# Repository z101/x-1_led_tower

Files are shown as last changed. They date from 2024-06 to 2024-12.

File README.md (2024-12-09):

# x-1_led_tower
This is an electronic LED sculpture project, stylized as some generic telecommunication tower and inspired by @mohitbhoite cool works.
The project will be break down to next parts:
1. **Electronic circuit**. Developed in KiCAD. Circuit from Frank Sichla's book. SPICE models for simulation taken from Internet
2. **3D model**. Developed in FreeCAD
3. **Assembly**. The most interesting part - building sculpture itself

## KiCAD circuit version 1
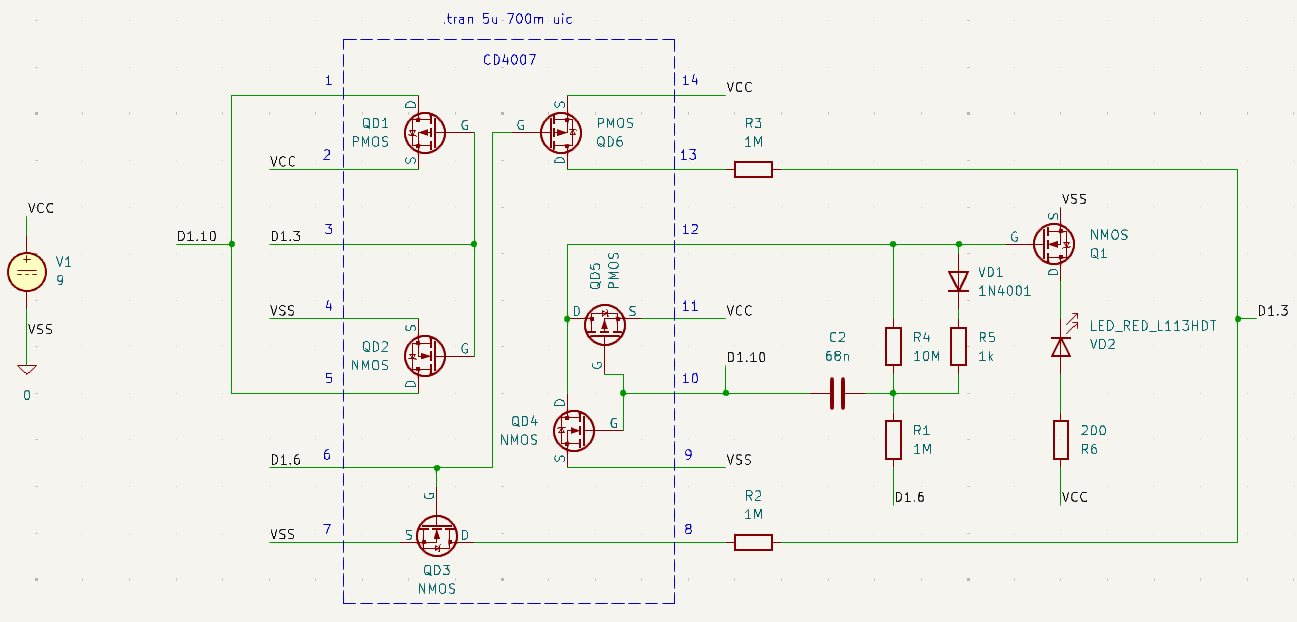
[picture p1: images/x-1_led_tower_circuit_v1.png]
x-1_led_tower circuit v1 KiCAD prototype


## KiCAD circuit SPICE flash spike simulation version 1
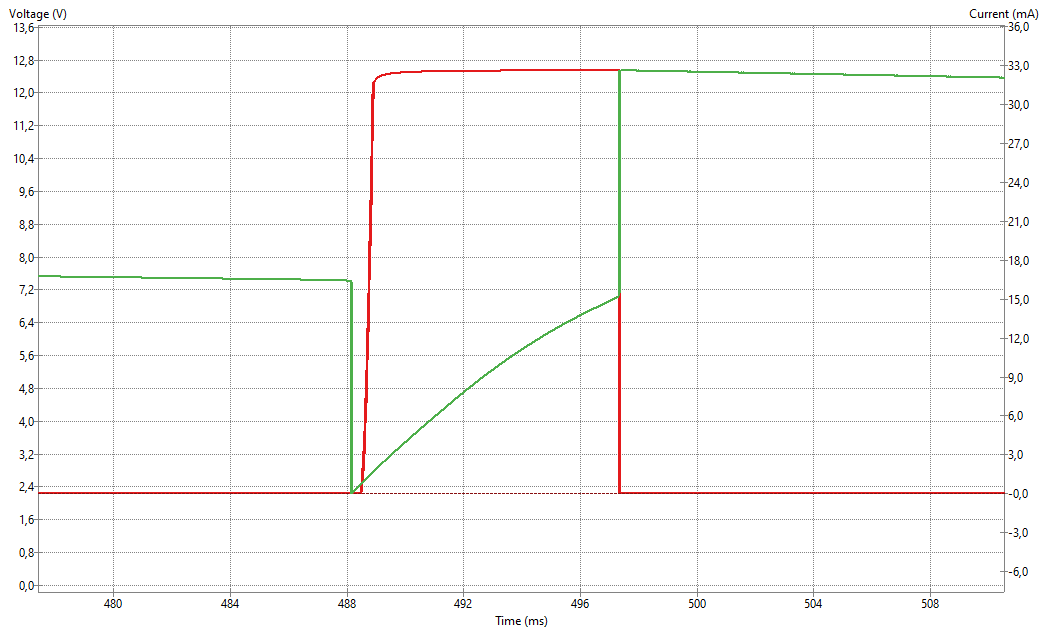
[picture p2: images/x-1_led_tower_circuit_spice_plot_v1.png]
x-1_led_tower circuit SPICE Simulation Plot v1 KiCAD prototype


## FreeCAD 3D prototype version 1
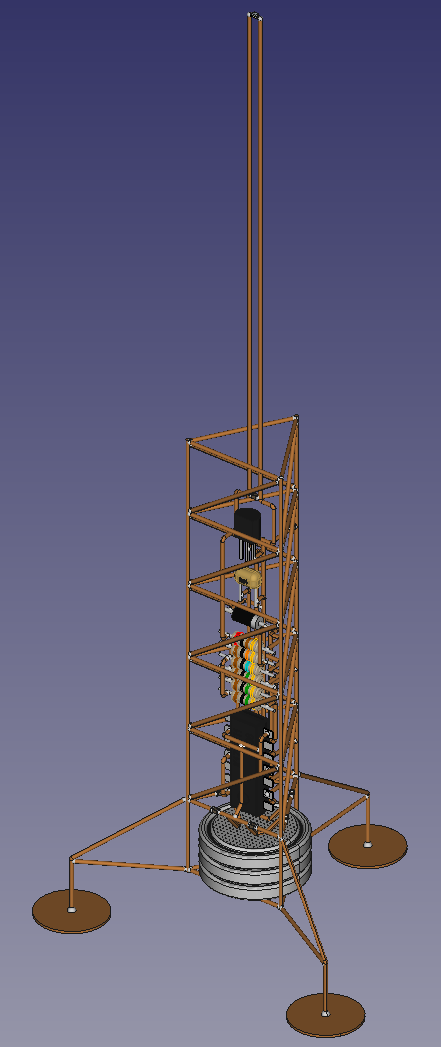
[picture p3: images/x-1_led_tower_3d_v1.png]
x-1_led_tower 3d v1 FreeCAD prototype


## Initial conditions changed
Due to a number of reasons, I can't solder at home yet. Therefore, I decided to redesign the tower project for assembly via crimping.

## FreeCAD 3D prototype version 2
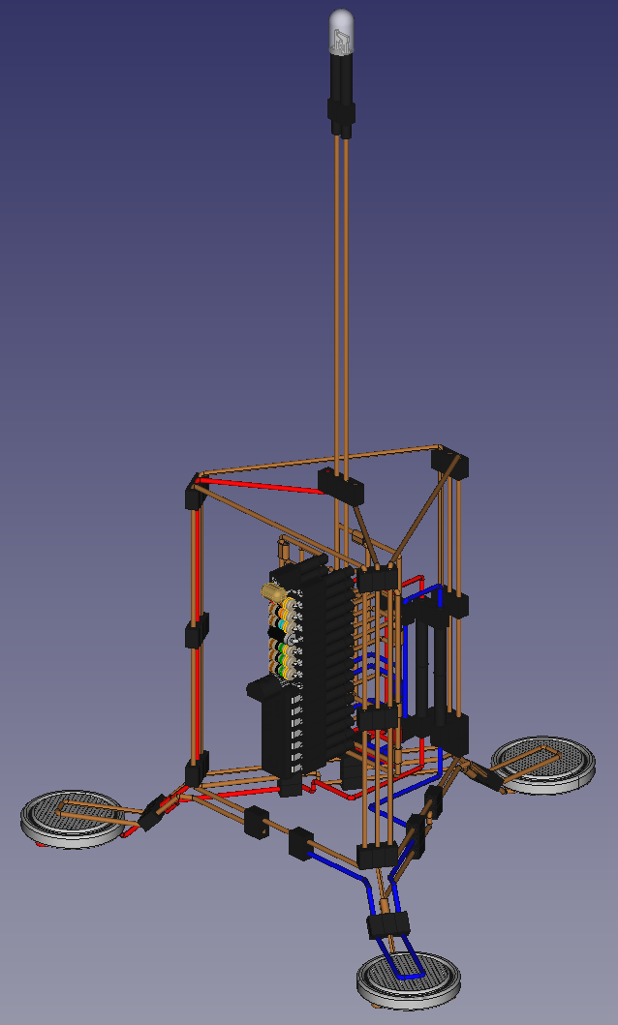
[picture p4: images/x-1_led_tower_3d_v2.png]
x-1_led_tower 3d v2 FreeCAD prototype


## FreeCAD 3D prototype version 2 assembly (failed)
Assembling the sculpture neatly using the blueprints of v2 turned out to be too difficult for me.  
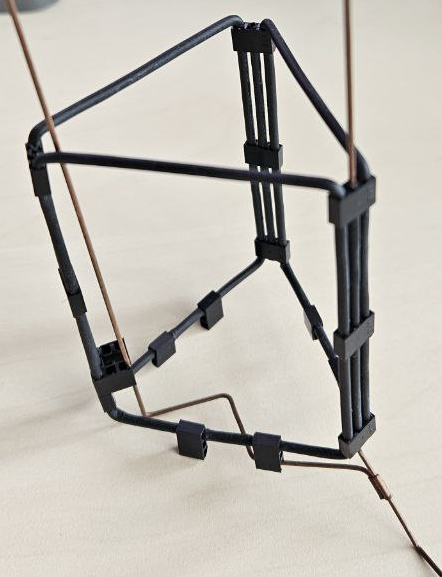
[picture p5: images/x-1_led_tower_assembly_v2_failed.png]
x-1_led_tower assembly v2 failed


## FreeCAD 3D prototype version 3
I abandoned v2 and decided to remake it into v3 - lightweight and simplified.  
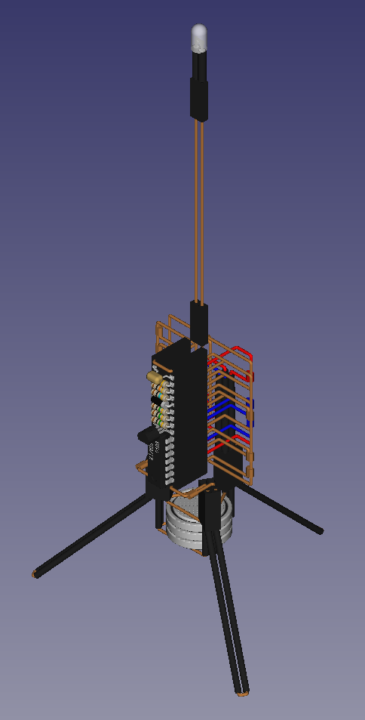
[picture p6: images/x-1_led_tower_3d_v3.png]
x-1_led_tower 3d v3 FreeCAD prototype


## FreeCAD 3D prototype version 3 assembly (failed)
Another fail with assembling triangle holder and bending. Threw it away...

## FreeCAD 3D prototype version 4
Another remake v4 - simplified for assembly  
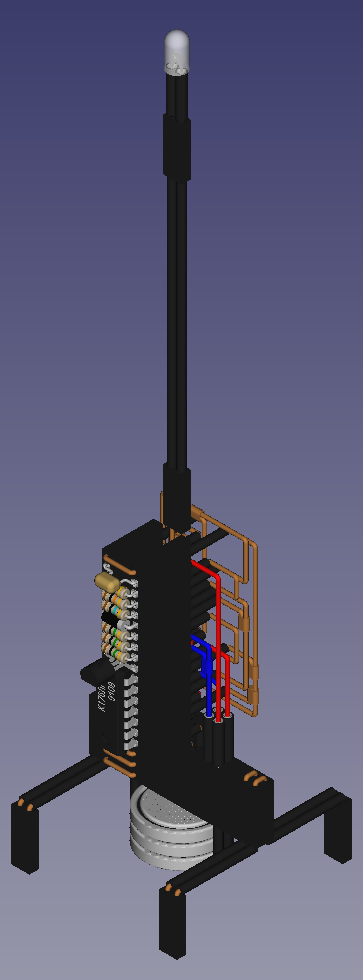
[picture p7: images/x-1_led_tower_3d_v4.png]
x-1_led_tower 3d v4 FreeCAD prototype


## FreeCAD 3D prototype version 4 assembly (abandoned)
I started the assembly, but only made the base, because I found a way to go back to soldering, to the original version of the sculpture.  
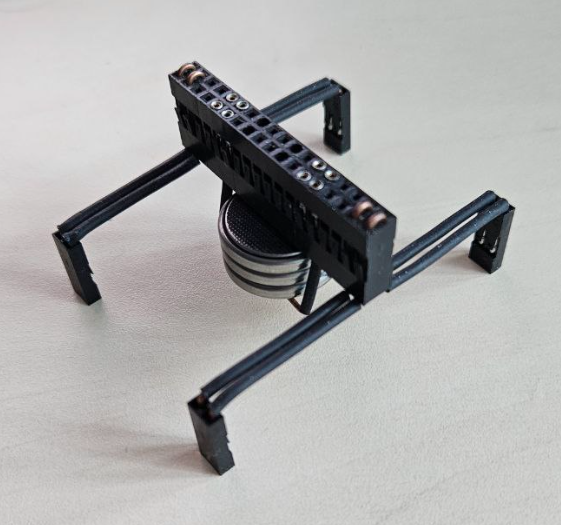
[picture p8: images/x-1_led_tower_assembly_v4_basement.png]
x-1_led_tower assembly v4 basement


## FreeCAD 3D prototype version 1.1
At first I tried soldering with pine rosin. The joints were quite neat, but there was too much solid rosin residue that could not be washed off with isopropyl alcohol, and it was not possible to remove all the residue mechanically. I gave up on this flux.  
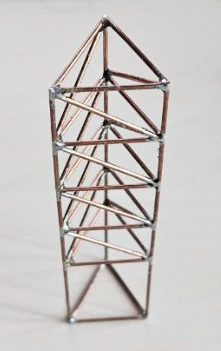
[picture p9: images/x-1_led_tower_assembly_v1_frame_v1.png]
x-1_led_tower assembly v1 frame v1


## FreeCAD 3D prototype version 1.1 (new flux)
I switched to liquid flux from Interflux (RP-65). I applied it with an applicator with a brush. The joints turned out nice and clean. But I failed again on soldering the negative battery holder. The 0603 SMD capacitors I wanted to use as separators turned out to be too fragile, the leads were torn off under load. So I decided to abandon the original idea again and move on to version 5 of the sculpture with a completely redesigned battery holder.  
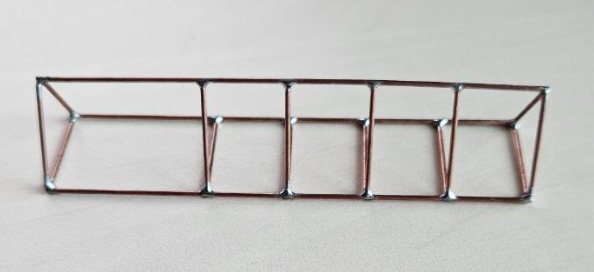
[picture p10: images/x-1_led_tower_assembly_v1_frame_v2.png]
x-1_led_tower assembly v1 frame v2


## FreeCAD 3D prototype version 5
Another remake v5 - improved battery holders and overall sculpture view.  
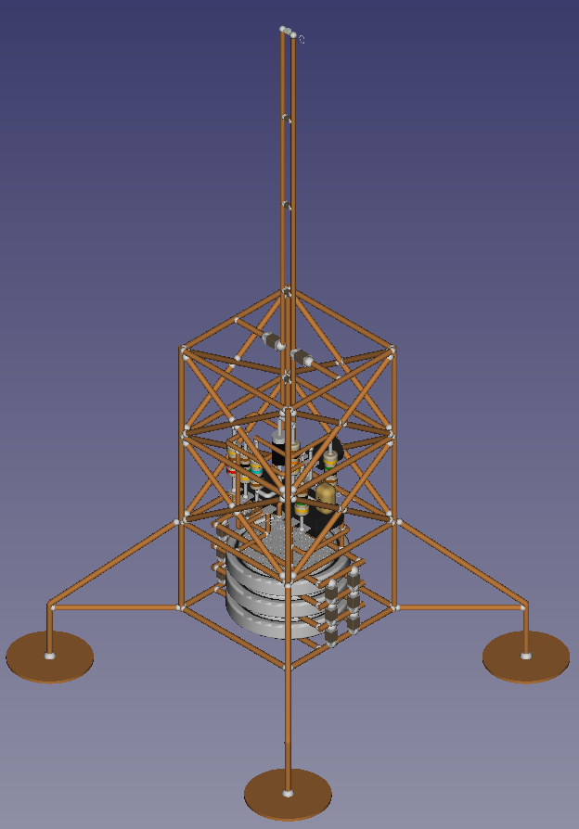
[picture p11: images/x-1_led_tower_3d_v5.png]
x-1_led_tower 3d v5 FreeCAD prototype


## FreeCAD 3D prototype version 5 assembly (failed)
I started the build of version 5 with the battery holder as the most controversial part of the design. The goal was to get independent sections for each CR2032. Unfortunately, the ceramic 1206 SMD decoupling capacitors fell apart when I inserted the batteries.  
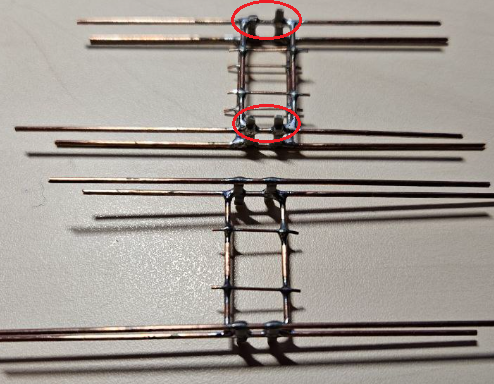
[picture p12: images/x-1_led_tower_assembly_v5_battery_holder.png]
x-1_led_tower assembly v5 battery holder


## FreeCAD 3D prototype version 5.1
Another remake v5.1 - combined battery holder (with fewer SMD 1206 capacitors).  
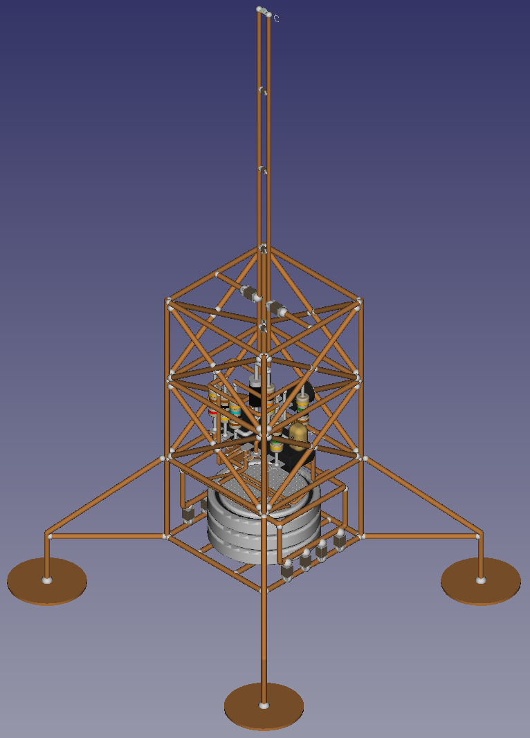
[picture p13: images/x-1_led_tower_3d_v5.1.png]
x-1_led_tower 3d v5.1 FreeCAD prototype


## FreeCAD 3D prototype version 5.1 assembly (failed)
The assembly of the holder of this version also failed. Even at the soldering stage. The SMD capacitors turned out to be too thin and fragile, and fell apart when trying to solder the holder to the side of the frame.  
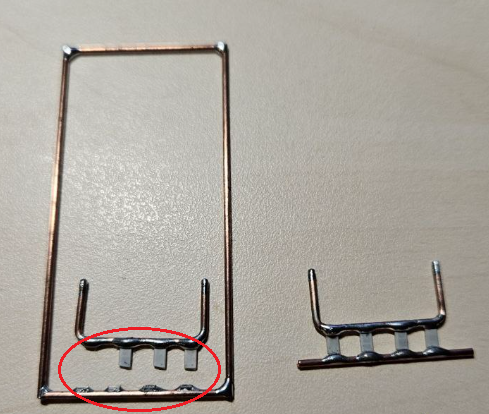
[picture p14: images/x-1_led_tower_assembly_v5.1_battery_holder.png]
x-1_led_tower assembly v5.1 battery holder


## FreeCAD 3D prototype version 5.2
Another remake v5.2 - replacing SMD capacitors by its DIP analogs.  
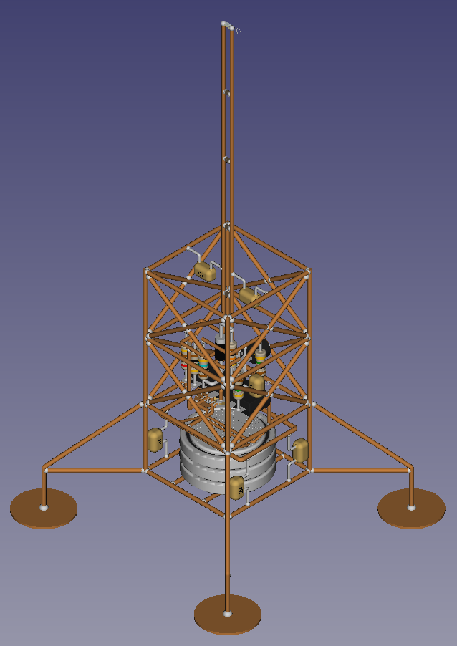
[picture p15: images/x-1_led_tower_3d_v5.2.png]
x-1_led_tower 3d v5.2 FreeCAD prototype


## FreeCAD 3D prototype version 5.2 assembly (success, finally! :)
At first I wanted to replace the thin and fragile 1206 capacitors with thiker 1210 ones. But then I decided to use "more durable" DIP ceramic capacitors with low capacitance. With them I managed to successfully complete soldering the entire sculpture.  
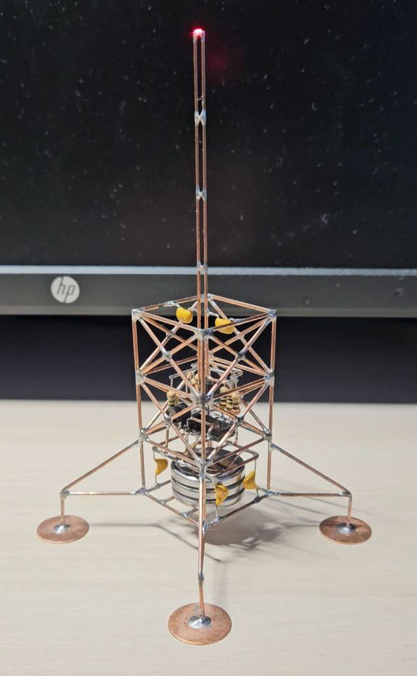
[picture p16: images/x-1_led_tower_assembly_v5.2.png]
x-1_led_tower assembly v5.2
  

## Simulation vs Reality
The simulated results of the voltage drop on the resistor R6 at the moment of LED flashes in KiCAD practically the same with the actual values taken by the Rigol oscilloscope (DHO814). However, the frequency of flashes is very different: ~1.5 Hz for simulation and ~0.25 Hz for the real circuit. I haven't figured out the reasons yet - I decided to leave it as is. The blinking is not annoying. Let's see how long it works without replacing the batteries.  
  
Simulated R6 flash voltage drop:  
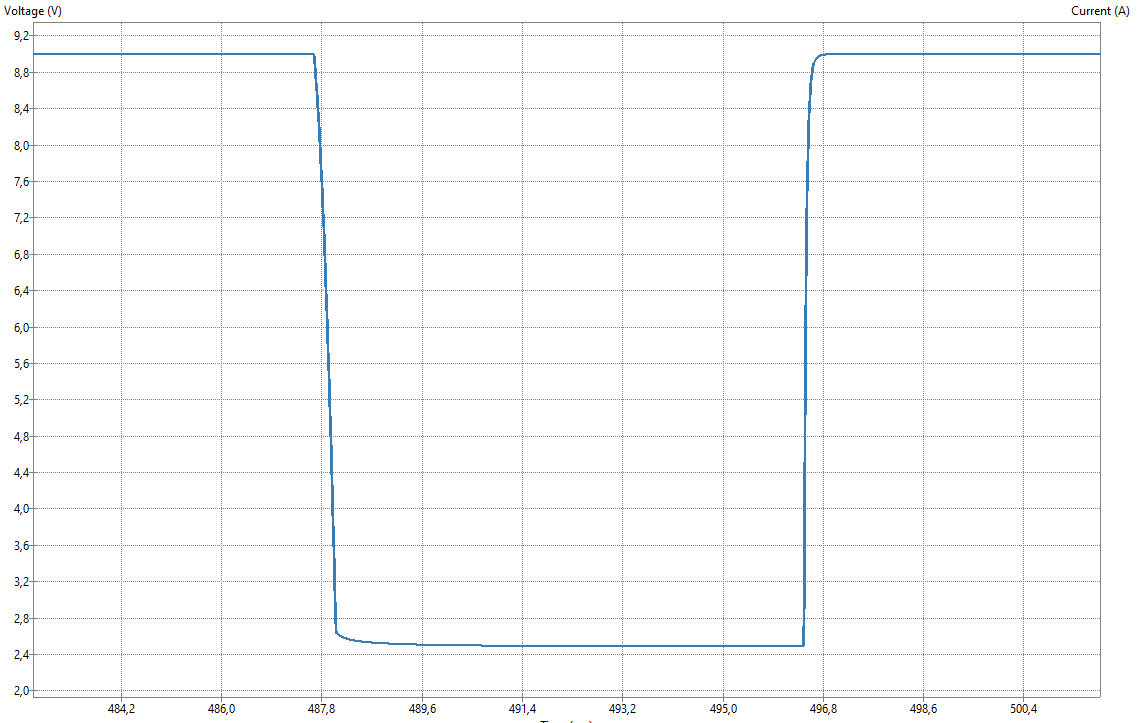
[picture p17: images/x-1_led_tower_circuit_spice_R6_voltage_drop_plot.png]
x-1_led_tower_circuit_spice_R6_voltage_drop_plot
  
  
Real R6 flash voltage drop:  
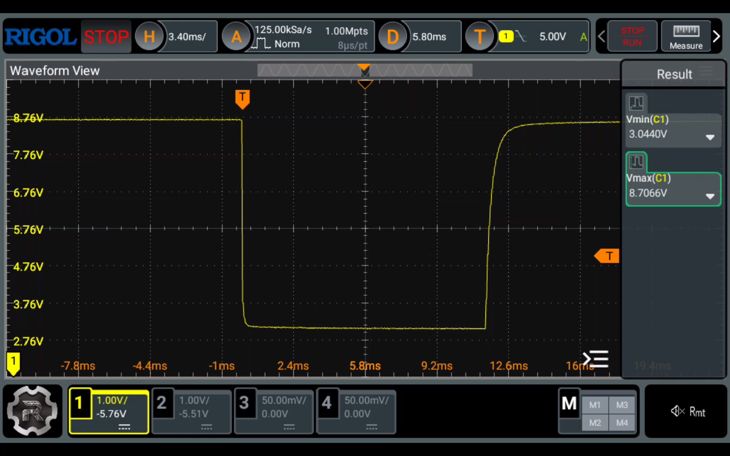
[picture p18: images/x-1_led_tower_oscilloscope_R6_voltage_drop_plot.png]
x-1_led_tower_oscilloscope_R6_voltage_drop_plot
  

## Summary
Overall, I am pleased with the result. The circuit is, of course, very trivial. But it is OK for the first time.  
  
 - **What I liked about assembling the sculpture**
   - I liked to solder with liquid flux Interflux RF65. It is very convenient to apply with an applicator with a brush. It does not smell, have no residue indeed
   - The following really helped in the work: a jewelry third hand, a steel plate with round neodymium magnets, a steel corner plate, thin curved tweezers
   - The wire frame looks nice
 - **What needs to be worked on**
   - The soldering quality is still terrible and far from beautiful joints - I need to practice more (especially when many conductors converge at one point). Considering that this is my first experience in soldering, there is room for growth :)
   - The wire with a diameter of 1 mm is too thick for the frame. In the future, I will try 0.8 mm
   - The assembly quality of the circuit itself (from DIP parts). The assembly of the circuit does not look neat. It is necessary to think about "flattening" using medium or large size SMD components (so that their soldering is not a pain)

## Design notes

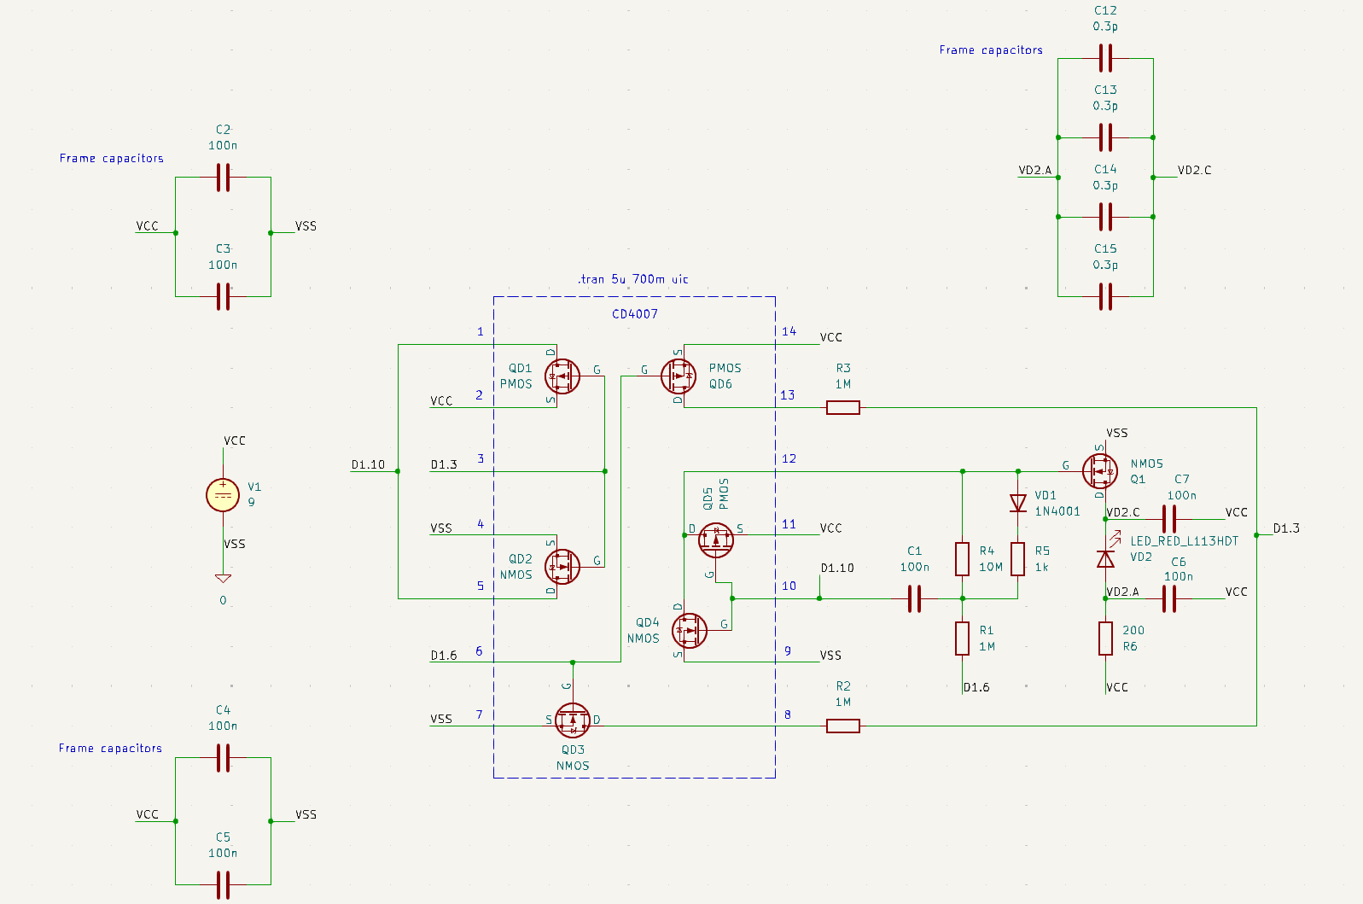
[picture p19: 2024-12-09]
images/x-1_led_tower_circuit_v1.1.png

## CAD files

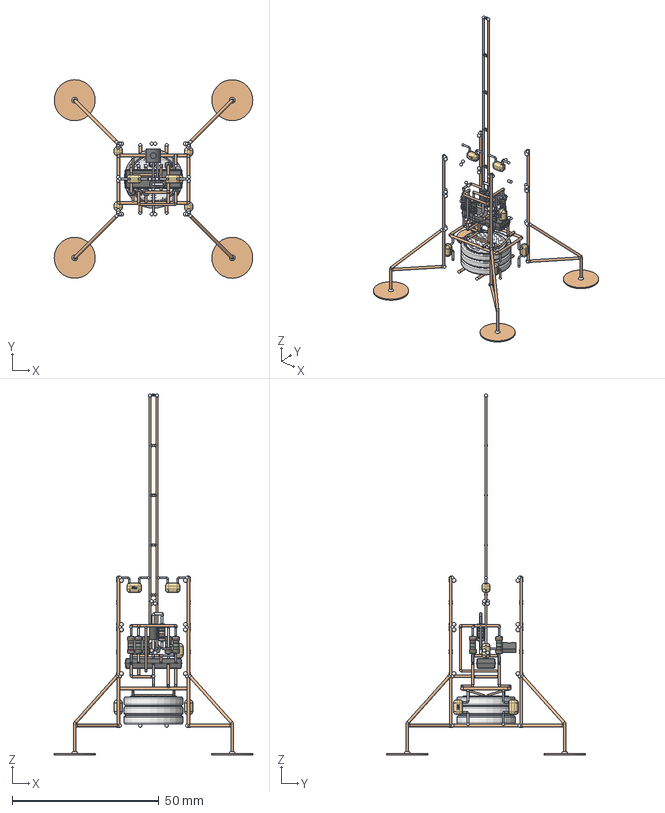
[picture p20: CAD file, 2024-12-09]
3d/x-1_led_tower.v5.2.FCStd
67.7 x 67.7 x 123.0 mm
Pillar Right - Basement
Basement Plus - Basement Front028
Basement Plus - Basement Front025
Pillar Right - Basement002
Pillar Right - Basement001
Basement Plus - Basement Front026
Basement Plus - Basement Front027
Pillar Right - Basement003
Pillar Back - Soldering Bottom Near011
Pillar Right - Basement Soldering
Pillar Right - Basement Soldering003
Pillar Back - Soldering Bottom Near012
Pillar Back - Soldering Bottom Near010
Pillar Back - Soldering Bottom Near005
Pillar Back - Soldering Bottom Near001
Pillar Back - Soldering Bottom Near002
Pillar Back - Soldering Bottom Near003
Pillar Right - Basement Soldering001
Pillar Back - Soldering Bottom Near004
Pillar Back - Soldering Bottom Near006
Pillar Right - Basement Soldering002
Pillar Back - Soldering Bottom Near007
Pillar Back - Soldering Bottom Near008
Pillar Back - Soldering Bottom Near009
Vertical 1
Vertical 002
Vertical 003
Vertical 004
Basement Plus - Basement Front007
Basement Plus - Basement Front006
Vertical 009
Basement Plus - Basement Front032
Vertical 010
Basement Plus - Basement Front033
Basement Plus - Basement Front034
Basement Plus - Basement Front035
Vertical 011
Basement Plus - Basement Front036
Vertical 012
Basement Plus - Basement Front037
Pillar Back - Soldering Bottom Far010
Pillar Back - Soldering Bottom Far014
Pillar Back - Soldering Bottom Far018
Pillar Back - Soldering Bottom Far022
Pillar Back - Soldering Bottom Far224
Pillar Back - Soldering Bottom Far225
Pillar Back - Soldering Bottom Far226
Pillar Back - Soldering Bottom Far227
Pillar Back - Soldering Bottom Far232
Pillar Back - Soldering Bottom Far233
Pillar Back - Soldering Bottom Far234
Pillar Back - Soldering Bottom Far235
Pillar Back - Soldering Bottom Far236
Pillar Back - Soldering Bottom Far237
Pillar Back - Soldering Bottom Far238
Pillar Back - Soldering Bottom Far239
Insulator
Minus
Plus
Insulator_2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

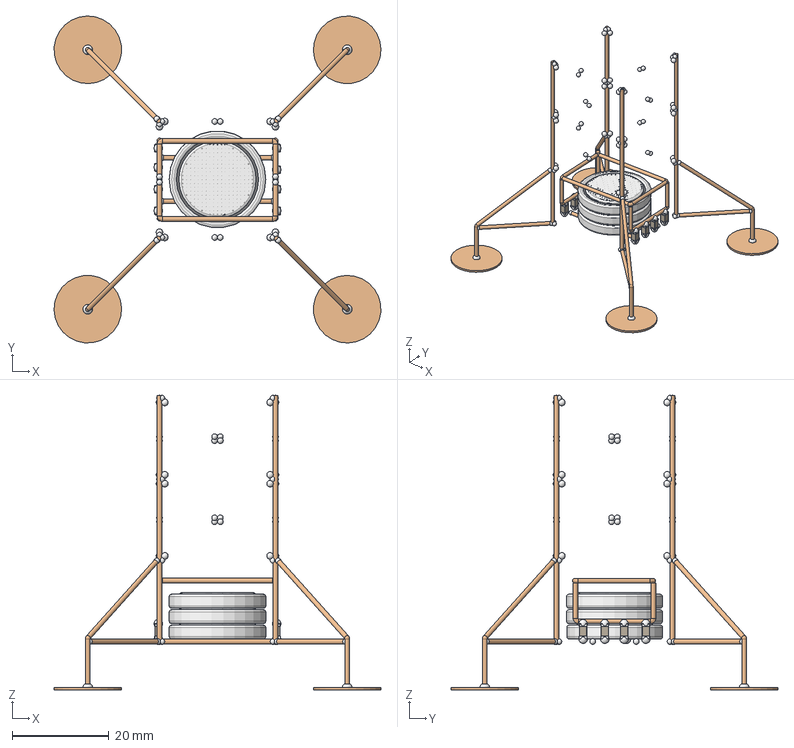
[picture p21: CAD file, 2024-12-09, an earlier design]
3d/x-1_led_tower.v5.FCStd
67.7 x 67.7 x 61.0 mm
Pillar Right - Basement
Basement Plus - Basement Front028
Basement Plus - Basement Front025
Pillar Right - Basement002
Pillar Right - Basement001
Basement Plus - Basement Front026
Basement Plus - Basement Front027
Pillar Right - Basement003
Pillar Back - Soldering Bottom Near011
Pillar Right - Basement Soldering
Pillar Right - Basement Soldering003
Pillar Back - Soldering Bottom Near012
Pillar Back - Soldering Bottom Near010
Pillar Back - Soldering Bottom Near005
Pillar Back - Soldering Bottom Near001
Pillar Back - Soldering Bottom Near002
Pillar Back - Soldering Bottom Near003
Pillar Right - Basement Soldering001
Pillar Back - Soldering Bottom Near004
Pillar Back - Soldering Bottom Near006
Pillar Right - Basement Soldering002
Pillar Back - Soldering Bottom Near007
Pillar Back - Soldering Bottom Near008
Pillar Back - Soldering Bottom Near009
Vertical 1
Vertical 002
Vertical 003
Vertical 004
Basement Plus - Basement Front007
Basement Plus - Basement Front006
Basement Plus - Basement Front010
Pillar Back - Soldering Bottom Far010
Pillar Back - Soldering Bottom Far014
Pillar Back - Soldering Bottom Far018
Pillar Back - Soldering Bottom Far022
Pillar Back - Soldering Bottom Far030
Pillar Back - Soldering Bottom Far032
Pillar Back - Soldering Bottom Far033
Pillar Back - Soldering Bottom Far034
Pillar Back - Soldering Bottom Far035
Pillar Back - Soldering Bottom Far036
Контакты002
Корпус002
Контакты
Корпус
Контакты001
Корпус001
Контакты003
Корпус003
Insulator
Minus
Plus
Insulator_2
Minus_2
Plus_2
Insulator_3
Minus_3
Plus_3
Pillar Back - Soldering Bottom Far047
Pillar Back - Soldering Bottom Far048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

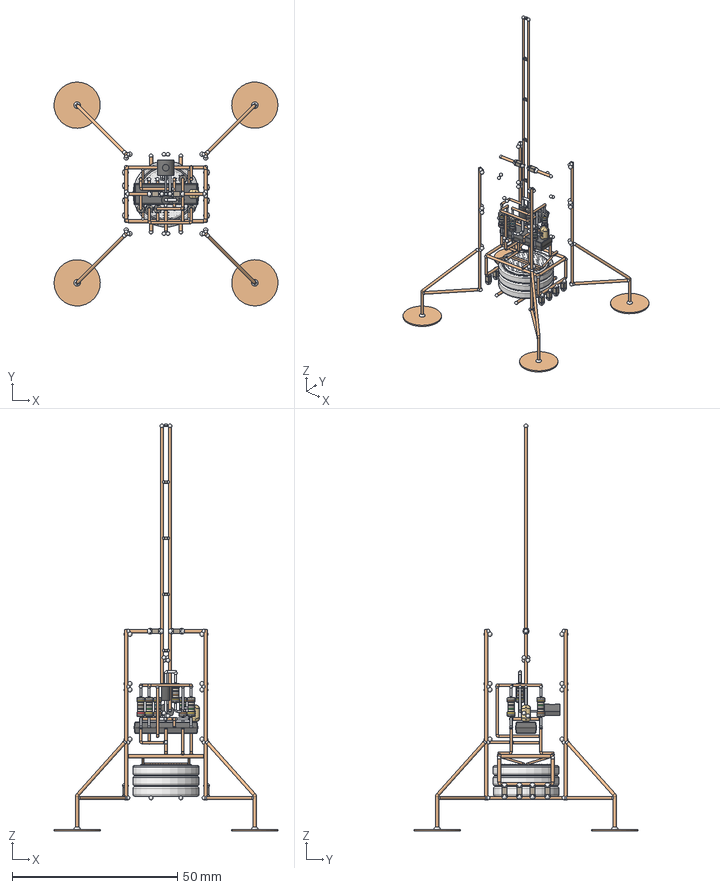
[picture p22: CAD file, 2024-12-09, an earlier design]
3d/x-1_led_tower.v5.1.FCStd
67.7 x 67.7 x 123.0 mm
Pillar Right - Basement
Basement Plus - Basement Front028
Basement Plus - Basement Front025
Pillar Right - Basement002
Pillar Right - Basement001
Basement Plus - Basement Front026
Basement Plus - Basement Front027
Pillar Right - Basement003
Pillar Back - Soldering Bottom Near011
Pillar Right - Basement Soldering
Pillar Right - Basement Soldering003
Pillar Back - Soldering Bottom Near012
Pillar Back - Soldering Bottom Near010
Pillar Back - Soldering Bottom Near005
Pillar Back - Soldering Bottom Near001
Pillar Back - Soldering Bottom Near002
Pillar Back - Soldering Bottom Near003
Pillar Right - Basement Soldering001
Pillar Back - Soldering Bottom Near004
Pillar Back - Soldering Bottom Near006
Pillar Right - Basement Soldering002
Pillar Back - Soldering Bottom Near007
Pillar Back - Soldering Bottom Near008
Pillar Back - Soldering Bottom Near009
Vertical 1
Vertical 002
Vertical 003
Vertical 004
Basement Plus - Basement Front007
Basement Plus - Basement Front006
Basement Plus - Basement Front010
Vertical 005
Vertical 006
Vertical 007
Vertical 008
Basement Plus - Basement Front031
Vertical 009
Basement Plus - Basement Front032
Vertical 010
Basement Plus - Basement Front033
Basement Plus - Basement Front034
Basement Plus - Basement Front035
Vertical 011
Basement Plus - Basement Front036
Vertical 012
Basement Plus - Basement Front037
Pillar Back - Soldering Bottom Far010
Pillar Back - Soldering Bottom Far014
Pillar Back - Soldering Bottom Far018
Pillar Back - Soldering Bottom Far022
Pillar Back - Soldering Bottom Far030
Pillar Back - Soldering Bottom Far032
Pillar Back - Soldering Bottom Far033
Pillar Back - Soldering Bottom Far034
Pillar Back - Soldering Bottom Far035
Pillar Back - Soldering Bottom Far036
Pillar Back - Soldering Bottom Far214
Pillar Back - Soldering Bottom Far215
Pillar Back - Soldering Bottom Far216
Pillar Back - Soldering Bottom Far217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

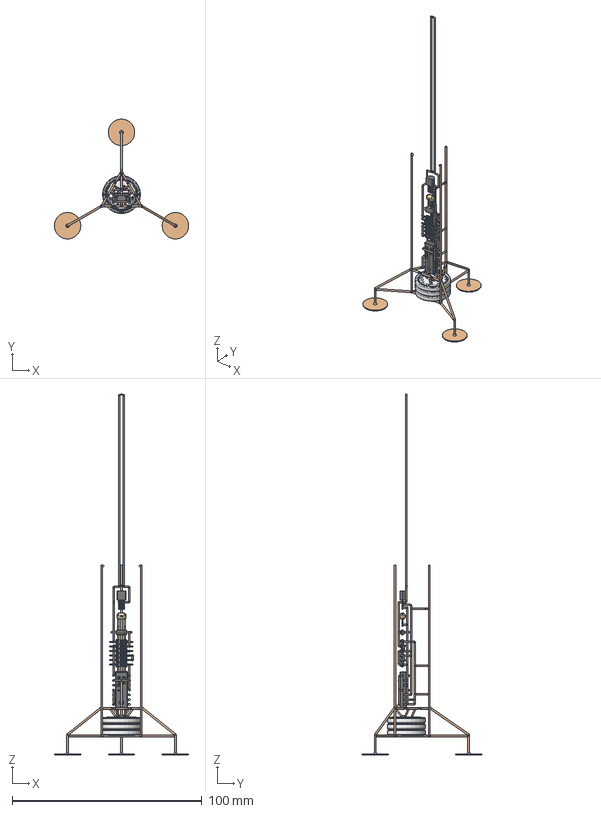
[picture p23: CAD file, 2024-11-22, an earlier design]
3d/x-1_led_tower.v1.1.FCStd
70.8 x 63.2 x 190.2 mm
Vertical 1
Vertical 002
Vertical 003
Basement Plus - Basement Front
Basement Plus - Basement Front001
Basement Plus - Basement Front002
Pillar Back - Soldering Bottom Far001
Pillar Back - Soldering Bottom Far002
Pillar Back - Soldering Bottom Far003
Pillar Back - Soldering Bottom Far004
Pillar Back - Soldering Bottom Far005
Pillar Back - Soldering Bottom Far006
Basement Minus - Basement Left - Sub Basement Near
Basement Minus - Basement Front - Sub Basement Middle
Holder Front Left Near
Holder Front Left Far
Holder Front Right Near
Holder Side Right
Holder Front Right Far
Holder Side Left
Holder Front Left Middle
Holder Front Right Middle
Holder Side Middle
Basement Minus - Basement Left - Sub Basement Near001
Basement Minus - Basement Left - Sub Basement Near002
Basement Minus - Basement Front - Sub Basement Middle001
Basement Minus - Basement Left - Sub Basement Near003
Basement Minus - Basement Left - Sub Basement Near004
Basement Minus - Basement Front - Sub Basement Middle002
Basement Minus - Basement Left - Sub Basement Near005
Holder Side Left - Soldering
Holder Front Left Far - Soldering
Holder Side Right - Soldering
Holder Front Right Near - Soldering
Holder Front Left Near - Soldering
Holder Front Right Far - Soldering
Holder Front Left Far - Soldering002
Holder Front Left Far - Soldering003
Holder Front Left Far - Soldering004
Holder Front Left Far - Soldering005
Holder Front Left Far - Soldering008
Holder Front Left Far - Soldering009
Holder Front Left Far - Soldering010
Holder Front Left Far - Soldering011
Holder Front Left Far - Soldering014
Holder Front Left Far - Soldering015
Holder Front Left Far - Soldering016
Holder Front Left Far - Soldering017
Pillar Back - Basement
Pillar Back - Bottom
Pillar Back - Top
Pillar Left - Basement
Pillar Left - Top
Pillar Left - Bottom
Pillar Right - Basement
Pillar Right - Top
Pillar Right - Bottom
Pillar Right - Basement Soldering
Pillar Right - Soldering Top
Pillar Right - Soldering Bottom Far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

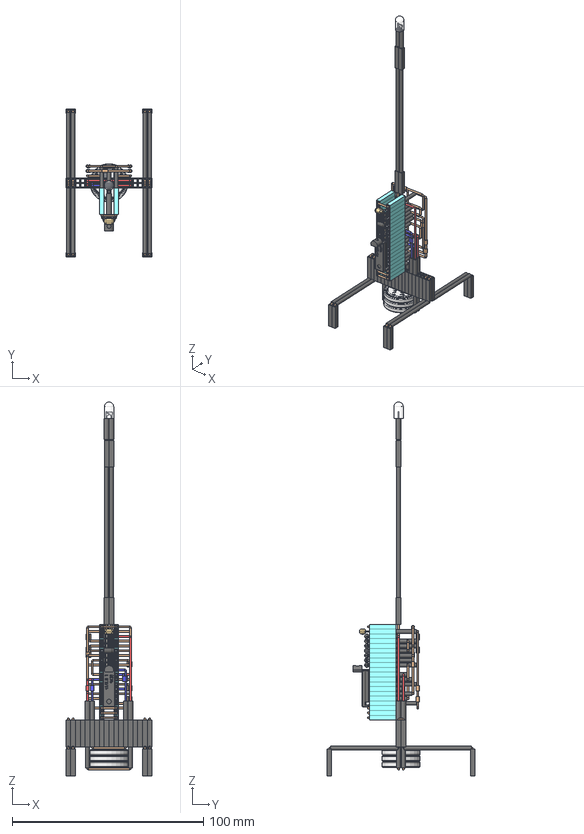
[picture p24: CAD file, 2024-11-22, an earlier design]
3d/x-1_led_tower.v4.FCStd
45.0 x 77.4 x 195.4 mm
Holder_Full_Size023
Holder_Full_Size024
Holder_Full_Size025
Holder_Full_Size026
Holder_Full_Size027
Holder_Full_Size028
Holder_Full_Size029
Holder_Full_Size030
Holder_Full_Size031
Holder_Full_Size032
Holder_Full_Size033
Holder_Full_Size034
Holder_Full_Size035
Holder_Full_Size036
Holder_Full_Size037
Holder_Full_Size038
Holder_Full_Size039
Holder_Full_Size040
Holder_Full_Size041
Holder_Full_Size042
Holder_Full_Size043
Holder_Full_Size044
Holder_Full_Size045
Holder_Full_Size046
Holder_Full_Size047
Holder_Full_Size048
Holder_Full_Size049
Holder_Full_Size050
Holder_Full_Size107
Holder_Full_Size108
Holder_Full_Size109
Holder_Full_Size110
Holder_Full_Size111
Holder_Full_Size112
Holder_Full_Size113
Holder_Full_Size114
Tube215
Tube216
Tube217
Tube218
Tube219
Tube220
Tube221
Tube222
Constuction - Wire Corners - 1.118
Constuction - Wire Corners - 1.119
Constuction - Wire Corners - 1.120
Constuction - Wire Corners - 1.121
Constuction - Wire Corners - 1.122
Constuction - Wire Corners - 1.123
Constuction - Wire Corners - 1.124
Constuction - Wire Corners - 1.125
Constuction - Wire Corners - 1.126
Constuction - Wire Corners - 1.127
Tube223
Frame_Minus_Socket034
Tube224
Frame_Minus_Socket035
Holder_Full_Size115
Holder_Full_Size116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

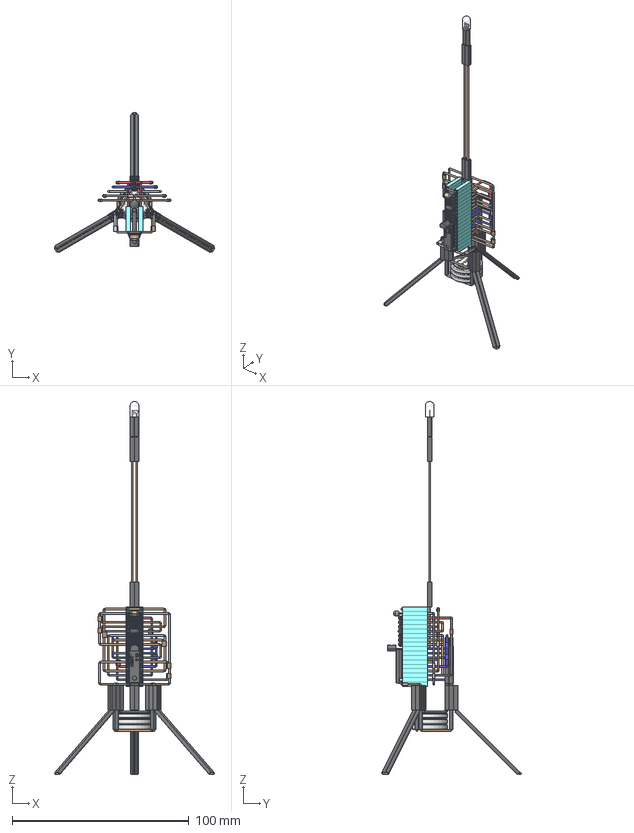
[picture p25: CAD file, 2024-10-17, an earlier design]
3d/x-1_led_tower.v3.FCStd
90.6 x 79.0 x 211.0 mm
Holder_Full_Size001
Holder_Full_Size002
Holder_Full_Size003
Holder_Full_Size004
Holder_Full_Size005
Holder_Full_Size006
Holder_Full_Size007
Holder_Full_Size008
Holder_Full_Size009
Holder_Full_Size010
Holder_Full_Size011
Holder_Full_Size012
Holder_Full_Size015
Holder_Full_Size016
Holder_Full_Size017
Holder_Full_Size018
Holder_Full_Size021
Holder_Full_Size022
Constuction_WireCorners_1.001
Constuction_WireCorners_1.002
Tube125
Tube127
Constuction_WireCorners_1.003
Constuction_WireCorners_1.004
Tube126
Tube129
Constuction_WireCorners_1.005
Constuction_WireCorners_1.006
Tube128
Tube130
Constuction_WireCorners_1.007
Constuction_WireCorners_1.008
Tube131
Tube132
Tube135
Constuction_WireCorners_1.011
Constuction_WireCorners_1.012
Tube136
Tube133
Constuction_WireCorners_1.009
Constuction_WireCorners_1.010
Tube134
Tube137
Tube138
Constuction_WireCorners_1.0_30_Degrees001
Constuction_WireCorners_1.0_30_Degrees002
Constuction_WireCorners_1.0_30_Degrees003
Constuction_WireCorners_1.0_30_Degrees004
Constuction_WireCorners_1.014
Constuction_WireCorners_1.015
Tube139
Tube140
Tube141
Tube142
Constuction_WireCorners_1.0_30_Degrees005
Constuction_WireCorners_1.0_30_Degrees006
Constuction_WireCorners_1.0_30_Degrees007
Constuction_WireCorners_1.0_30_Degrees008
Constuction_WireCorners_1.016
Constuction_WireCorners_1.017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

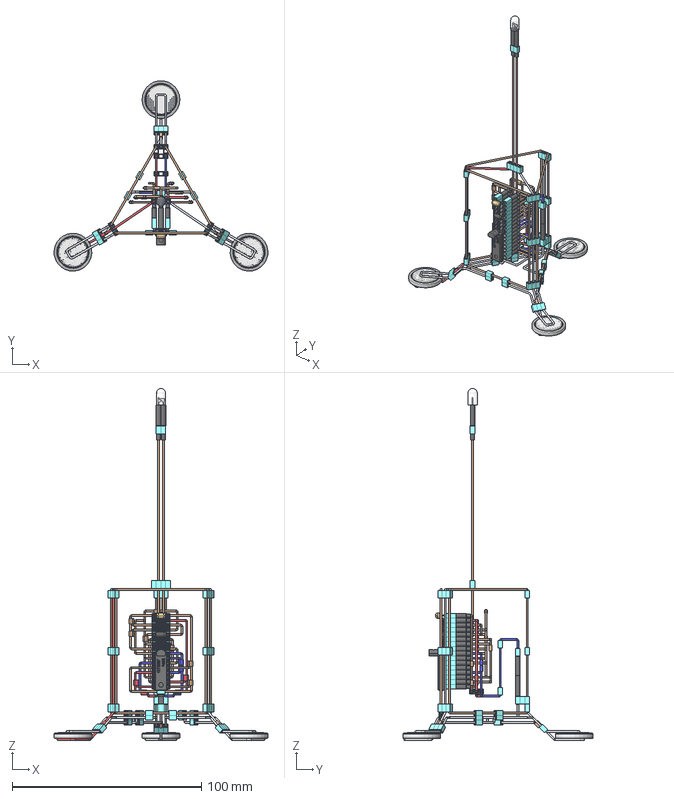
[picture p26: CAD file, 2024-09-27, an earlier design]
3d/x-1_led_tower.v2.FCStd
112.9 x 100.5 x 185.8 mm
Wall_Front
Wall_Plus
Wall_Minus
Frame_BatteryHolder_Back_Plus
Frame_BatteryHolder_Back_Minus
Frame_BatteryHolder_Right_Minus
Frame_BatteryHolder_Right_Plus
Frame_BatteryHolder_Left_Plus
Frame_BatteryHolder_Left_Minus
Frame_Power_Plus_Wire
Holder_1_Frame_Power_Separator
Holder_2_Basement_Front_Right
Holder_2_Basement_Front_Left
Holder_2_Basement_Right_Far
Holder_3_Battery_Interm
Holder_3_Battery_Minus
Holder_3_Battery_Plus
Holder_3_Basement_Left_Near
Holder_3_Basement_Left_Far
Holder_3_Basement_Right_Near
Holder_3_Wall_Back_Bottom
Holder_3_Wall_Back_Middle
Holder_3_Wall_Back_Top
Holder_3_Wall_Right_Bottom
Holder_3_Wall_Right_Middle
Holder_3_Wall_Right_Top
Holder_3_Wall_Left_Bottom
Holder_3_Wall_Left_Middle
Holder_3_Wall_Left_Top
Holder_3_Frame_Power_Minus
Holder_3_Frame_Power_Plus
Led_Holder_Insulator_Right_Small001
Led_Holder_Insulator_Right_Small002
Led_Holder_Insulator_Right_Small003
Led_Holder_Insulator_Right_Small004
Led_Holder_Insulator_Right_Small005
Led_Holder_Insulator_Right_Small006
Insulator_Front_Top_Right
Insulator_Front_Top_Left
Insulator_Left_Interim002
Frame_Plus_Insulator_Wire
Led_Holder_Insulator_Right_Small019
Led_Holder_Insulator_Right_Small020
Led_Holder_Insulator_Right_Small021
Insulator_Holder_Small_Right
Led_Holder_Insulator_Left_Small
Led_Holder_Insulator_Right_Small007
Led_Holder_Insulator_Right_Small008
Led_Holder_Insulator_Right_Small009
Led_Holder_Insulator_Right_Small010
Led_Holder_Insulator_Right_Small011
Led_Holder_Insulator_Right_Small012
Insulator_Left_Near_Top
Insulator_Left_Far_Top
Led_Holder_Insulator_Right_Small013
Led_Holder_Insulator_Right_Small014
Led_Holder_Insulator_Right_Small015
Led_Holder_Insulator_Right_Small016
Led_Holder_Insulator_Right_Small017
Led_Holder_Insulator_Right_Small018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

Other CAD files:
3d/x-1_led_tower.FCStd

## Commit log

2024-06-14 3d - add tech draw - frame elements
    [x-1_led_tower.FCStd]
2024-06-14 3d - add blueprints and assembly sequence
    [x-1_led_tower.FCStd]
2024-06-21 add KiCAD circuit
    [x-1_led_tower.FCStd, x-1_led_tower.kicad_sch]
2024-09-12 add 3d v2
    [x-1_led_tower.FCStd, x-1_led_tower.v2.FCStd]
2024-09-27 add 3d v3
    [x-1_led_tower.v2.FCStd, x-1_led_tower.v3.FCStd]
2024-10-17 fix v3
    [x-1_led_tower.v3.FCStd]
2024-12-09 v.5.2 final
    [x-1_led_tower.kicad_sch, x-1_led_tower.v5.1.FCStd, x-1_led_tower.v5.2.FCStd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]
